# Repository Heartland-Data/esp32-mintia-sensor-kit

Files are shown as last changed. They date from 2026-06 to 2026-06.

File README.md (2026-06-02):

# esp32-mintia-sensor-kit

本リポジトリは、MINTIAケースにESP32と各種センサを組み込む試作用ファームウェアの参考実装です。

Acconeer XM125（存在検知レーダー）、AMG8833（8×8 IRアレイ）、MLX90640（32×24 IRアレイ）の3種のセンサを制御し、計測データをBluetooth Classic (SPP) および UART でホストPCへ送信します。

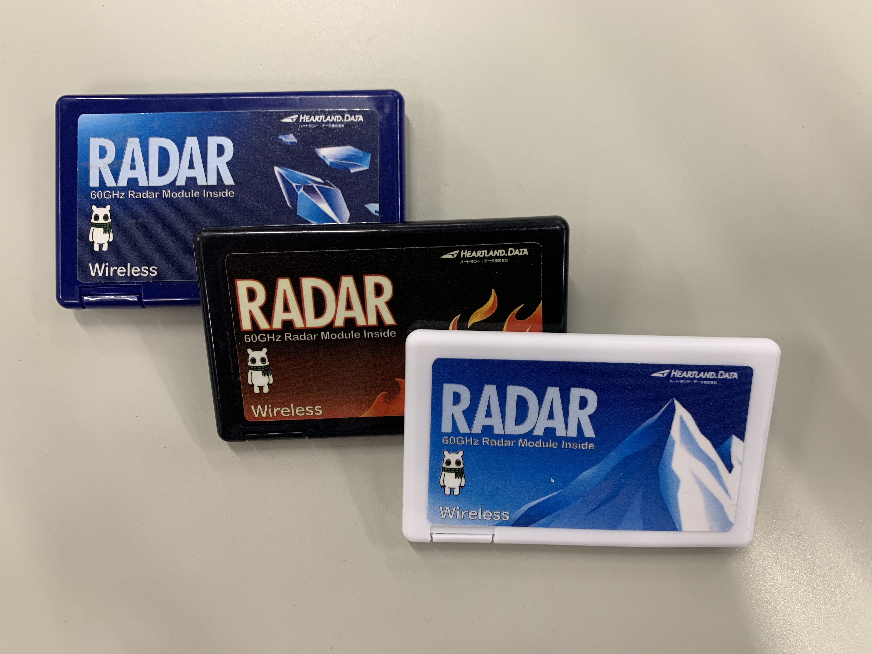
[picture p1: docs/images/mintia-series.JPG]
MINTIAケースシリーズ

MINTIAケース

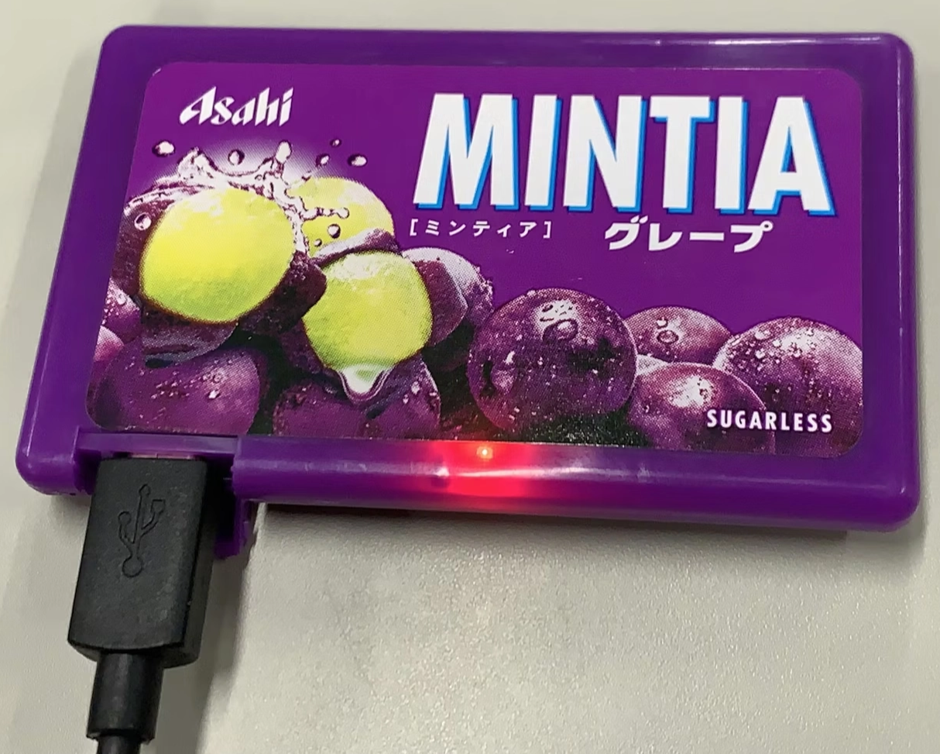
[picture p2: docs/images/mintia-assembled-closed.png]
MINTIAケース収納状態

MINTIAケースに基板を組み込んだ状態の外観です。

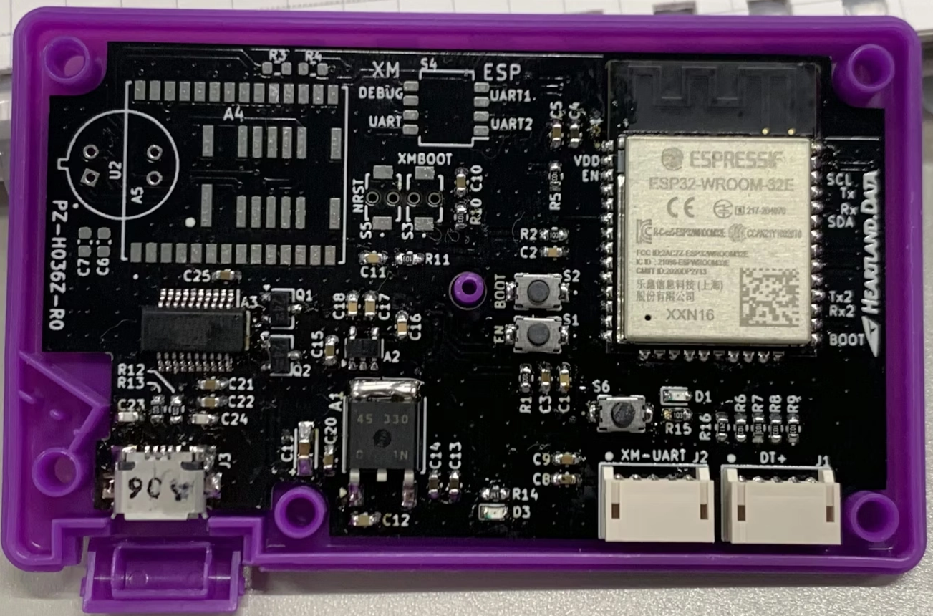
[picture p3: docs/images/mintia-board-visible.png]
MINTIAケース内部基板

ケース上部を開けると、内部の基板を確認できます。

ハードウェア構成、基板設計、部品実装などの詳細については、以下の解説記事を参照してください。

- [MINTIA(清涼菓子) へ ESP32 を組込む ~ 準備編 ~ - Qiita](https://qiita.com/TTL/items/94461dc0f962da8d8ca6)
- [MINTIA(清涼菓子) へ ESP32 を組込む ～ 回路、基板設計 ～ - Qiita](https://qiita.com/TTL/items/4987077ce9cf24eee11f)
- [MINTIA(清涼菓子) へ ESP32 を組込む ～ガーバー出力 ～ - Qiita](https://qiita.com/TTL/items/95624cc8908f53563718)
- [MINTIA(清涼菓子) へ ESP32 を組込む ～基板発注～ - Qiita](https://qiita.com/TTL/items/4f62d206479876ff367e)
- [MINTIA(清涼菓子) へ ESP32 を組込む ～基板到着 -> 部品実装～ - Qiita](https://qiita.com/TTL/items/9614f3e603545a89d696)

## 対応センサ

| センサ | 種別 | 解像度 / 検知方式 |
| --- | --- | --- |
| Acconeer XM125 | レーダーセンサー | I2C 接続、距離・存在検知 |
| AMG8833 (AMG88xx) | IRセンサー | I2C 接続、8×8 ピクセル |
| MLX90640 | IRセンサー | I2C 接続、32×24 ピクセル（768点） |

## ビルド環境

| 項目 | バージョン |
| --- | --- |
| ESP-IDF | v5.4.1 |
| ビルドシステム | CMake + idf.py |
| Bluetooth | Classic (SPP) — `sdkconfig.defaults` で設定済み |

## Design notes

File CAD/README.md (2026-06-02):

# 概要
本リポジトリは、Acconeer社製 60GHz Radar Unit "XM125" 及び "IR Sensor Array",
Espressif社 ESP32 Module を 清涼菓子 "MINTIA"ケースに収まる仕立ての回路及び基板データです。

## ハードウェア構成
* [Espressif ESP32](https://www.espressif.com/ja-jp/products/modules)
* [Acconeer](https://acconeer.com/products/) XM125 (60GHz Radar)
* IR Sensor Array
    * panasonic社 [AMG88](https://industrial.panasonic.com/jp/products/pt/grid-eye/models/AMG8833)
    * Melexis社 [MLX90640](https://www.melexis.com/en/product/MLX90640/far-infrared-thermal-sensor-array)

# ディレクトリ構造
[KiCAD](https://www.kicad.org/) 用 Data 及び PCB作成用ガーバーデータ一式

```
|   README.md
|   IR.kicad_sch
|   Main.kicad_sch
|   Power.kicad_sch
|   Radar.kicad_sch
|   Serial.kicad_sch
|   Work.kicad_pcb
|   Work.kicad_prl
|   Work.kicad_pro
|   Work.kicad_sch
|
\---GB
        PZ-H036Z-R1-B_Cu.gbl
        PZ-H036Z-R1-B_Mask.gbs
        PZ-H036Z-R1-B_Paste.gbp
        PZ-H036Z-R1-B_Silkscreen.gbo
        PZ-H036Z-R1-drl.rpt
        PZ-H036Z-R1-drl_map.gbr
        PZ-H036Z-R1-Edge_Cuts.gm1
        PZ-H036Z-R1-F_Cu.gtl
        PZ-H036Z-R1-F_Mask.gts
        PZ-H036Z-R1-F_Paste.gtp
        PZ-H036Z-R1-F_Silkscreen.gto
        PZ-H036Z-R1.drl
```

# ライセンス
MIT License

Copyright (c) 2026 Heartland Data Co., Ltd.

Permission is hereby granted, free of charge, to any person obtaining a copy of this software and associated documentation files (the "Software"), to deal in the Software without restriction, including without limitation the rights to use, copy, modify, merge, publish, distribute, sublicense, and/or sell copies of the Software, and to permit persons to whom the Software is furnished to do so, subject to the following conditions:

The above copyright notice and this permission notice shall be included in all copies or substantial portions of the Software.

THE SOFTWARE IS PROVIDED "AS IS", WITHOUT WARRANTY OF ANY KIND, EXPRESS OR IMPLIED, INCLUDING BUT NOT LIMITED TO THE WARRANTIES OF MERCHANTABILITY, FITNESS FOR A PARTICULAR PURPOSE AND NONINFRINGEMENT. IN NO EVENT SHALL THE AUTHORS OR COPYRIGHT HOLDERS BE LIABLE FOR ANY CLAIM, DAMAGES OR OTHER LIABILITY, WHETHER IN AN ACTION OF CONTRACT, TORT OR OTHERWISE, ARISING FROM, OUT OF OR IN CONNECTION WITH THE SOFTWARE OR THE USE OR OTHER DEALINGS IN THE SOFTWARE.

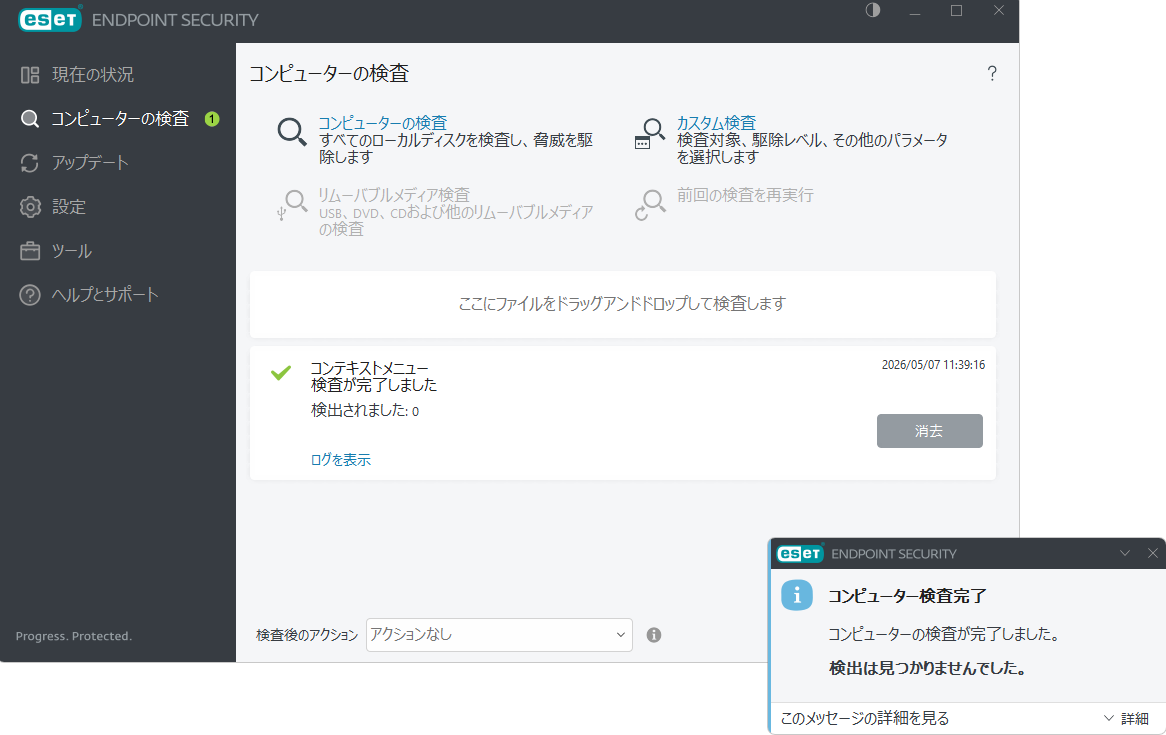
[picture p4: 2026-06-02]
CAD/ESET_Scan.png

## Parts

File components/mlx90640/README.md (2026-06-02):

# MLX90640 ESP32-IDF Library

このライブラリは、SparkFun の MLX90640 IR アレイセンサー用の ESP32-IDF ライブラリです。Arduino 環境向けのコードから ESP32-IDF 向けに移植されています。

## 特徴

- MLX90640 32x24 IR アレイセンサーの完全サポート
- ESP32-IDF I2C ドライバとの統合
- 温度計算と RAW IR イメージデータの取得
- 設定可能なリフレッシュレートと解像度
- 使いやすいサービスクラス

## ファイル構成

```
components/mlx90640/
├── CMakeLists.txt
├── README.md
├── include/
│   ├── mlx90640_api.h          # MLX90640 API関数
│   ├── mlx90640_i2c_driver.h   # I2C通信ドライバ
│   └── mlx90640_service.h      # 高レベルサービスクラス
├── mlx90640_api.c              # MLX90640 API実装
├── mlx90640_i2c_driver.c       # I2C通信ドライバ実装
└── mlx90640_service.c          # 高レベルサービス実装
```

## 使用方法

### 1. 基本的な初期化と温度取得

```c
#include "mlx90640_service.h"

void app_main()
{
    // 設定の初期化
    mlx90640_config_t config = MLX90640_DEFAULT_CONFIG();

    // サービスの初期化
    mlx90640_service_t *mlx_service = mlx90640_service_init(&config);
    if (mlx_service == NULL) {
        ESP_LOGE("APP", "Failed to initialize MLX90640 service");
        return;
    }

    // 温度データ配列 (24x32 = 768個)
    float temperatures[768];

    while (1) {
        // 温度データの取得
        esp_err_t ret = mlx90640_service_get_temperatures(mlx_service, temperatures);
        if (ret == ESP_OK) {
            // 温度データの処理
            for (int i = 0; i < 768; i++) {
                printf("%.2f,", temperatures[i]);
                if ((i + 1) % 32 == 0) printf("\n");
            }
        }

        vTaskDelay(pdMS_TO_TICKS(500)); // 500ms待機
    }

    // クリーンアップ
    mlx90640_service_deinit(mlx_service);
}
```

### 2. 既存のタスクシステムとの統合

```c
#include "mlx90640_service.h"

// タスククラスのヘッダで
class YourIrSensorTask {
private:
    mlx90640_service_t *mlx_service_;

public:
    bool Initialize() {
        mlx90640_config_t config = MLX90640_DEFAULT_CONFIG();
        // カスタム設定
        config.sda_pin = 21;
        config.scl_pin = 22;
        config.refresh_rate = 0x03; // 4Hz

        mlx_service_ = mlx90640_service_init(&config);
        return (mlx_service_ != nullptr);
    }

    void Run() {
        float temperatures[768];
        esp_err_t ret = mlx90640_service_get_temperatures(mlx_service_, temperatures);
        if (ret == ESP_OK) {
            // データをメッセージバッファに送信
            SendSensorData((uint8_t*)temperatures, sizeof(temperatures));
        }
    }

    ~YourIrSensorTask() {
        if (mlx_service_) {
            mlx90640_service_deinit(mlx_service_);
        }
    }
};
```

### 3. 低レベル API 使用例

```c
#include "mlx90640_api.h"
#include "mlx90640_i2c_driver.h"

void low_level_example()
{
    // I2C初期化
    MLX90640_I2CInit(I2C_NUM_0, 21, 22, 400000);

    uint8_t mlx_addr = 0x33;
    uint16_t eeMLX90640[832];
    paramsMLX90640 mlx90640;

    // EEPROM読み込み
    int status = MLX90640_DumpEE(mlx_addr, eeMLX90640);
    if (status != 0) {
        ESP_LOGE("MLX", "Failed to load system parameters");
        return;
    }

    // パラメータ抽出
    status = MLX90640_ExtractParameters(eeMLX90640, &mlx90640);
    if (status != 0) {
        ESP_LOGE("MLX", "Parameter extraction failed");
        return;
    }

    // リフレッシュレート設定
    MLX90640_SetRefreshRate(mlx_addr, 0x03); // 4Hz

    uint16_t mlx90640Frame[834];
    float mlx90640To[768];

    while (1) {
        // フレームデータ取得
        status = MLX90640_GetFrameData(mlx_addr, mlx90640Frame);
        if (status < 0) {
            ESP_LOGE("MLX", "GetFrame Error: %d", status);
            continue;
        }

        float vdd = MLX90640_GetVdd(mlx90640Frame, &mlx90640);
        float ta = MLX90640_GetTa(mlx90640Frame, &mlx90640);
        float tr = ta - 8; // 反射温度
        float emissivity = 0.95;

        // 温度計算
        MLX90640_CalculateTo(mlx90640Frame, &mlx90640, emissivity, tr, mlx90640To);

        // データ処理
        for (int x = 0; x < 768; x++) {
            printf("%.2f,", mlx90640To[x]);
        }
        printf("\n");

        vTaskDelay(pdMS_TO_TICKS(250));
    }
}
```

## 設定パラメータ

### リフレッシュレート

- 0x00: 0.5Hz
- 0x01: 1Hz
- 0x02: 2Hz
- 0x03: 4Hz (推奨)
- 0x04: 8Hz
- 0x05: 16Hz
- 0x06: 32Hz
- 0x07: 64Hz

### 解像度

- 0x00: 16 ビット
- 0x01: 17 ビット (推奨)
- 0x02: 18 ビット
- 0x03: 19 ビット

## ハードウェア接続

```
ESP32    MLX90640
-----    --------
3.3V  -> VCC
GND   -> GND
21    -> SDA
22    -> SCL
```

プルアップ抵抗（4.7kΩ）が SDA と SCL ラインに必要です。

## トラブルシューティング

### I2C 通信エラー

- 配線を確認してください
- プルアップ抵抗が正しく接続されているか確認してください
- I2C アドレス（デフォルト：0x33）を確認してください

### データ取得エラー

- センサーの電源投入後、100ms 以上待機してください
- フレームレート設定を下げてみてください

## ライセンス

このライブラリは **Apache License 2.0** の下でライセンスされています（`LICENSE` ファイル参照）。

### 著作権表示・帰属情報

本コードは以下の著作物を元に派生したものです。

| 著作物 | 著作権者 | ライセンス | URL |
|---|---|---|---|
| MLX90640 library (オリジナル) | © 2017 Melexis N.V. | Apache License 2.0 | https://github.com/melexis/mlx90640-library |
| Qwiic IR Array MLX90640 Firmware (Arduino 移植) | SparkFun Electronics | Apache License 2.0 ※ | https://github.com/sparkfun/Qwiic_IR_Array_MLX90640 |
| 本ライブラリ (ESP32-IDF 移植・改変) | © 2025 Heartland.Data Inc. | Apache License 2.0 | — |

※ SparkFun のファームウェアは Melexis の Apache License 2.0 ヘッダをそのまま維持しています。

Apache License 2.0 の全文は [http://www.apache.org/licenses/LICENSE-2.0](http://www.apache.org/licenses/LICENSE-2.0) を参照してください。

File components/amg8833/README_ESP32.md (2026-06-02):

# AMG88xx ESP32 Driver

ESP-IDF対応のAMG88xx赤外線温度センサードライバーです。

## 概要

このライブラリは、Panasonic AMG88xx (AMG8833) 赤外線アレイセンサーをESP32で使用するためのESP-IDF互換ドライバーです。Arduino環境の依存関係を取り除き、ESP-IDFのAPIを使用して実装されています。

## 特徴

- ESP-IDF v4.4以降対応
- C言語インターフェース
- 8x8ピクセルの温度データ読み取り
- サーミスタ温度読み取り
- 割り込み機能サポート
- 移動平均フィルタ
- パワーマネジメント
- フレームレート設定（1FPS/10FPS）

## ハードウェア要件

- ESP32系マイコン
- AMG8833赤外線アレイセンサー
- I2C接続（SCL, SDA）

## 配線

| AMG8833 | ESP32 |
|---|---|
| VDD | 3.3V  |
| GND | GND |
| SCL | GPIO22 (設定可能) |
| SDA | GPIO21 (設定可能) |
| INT | GPIO (オプション) |

## 使用方法

### 1. I2Cの初期化

```c
#include "driver/i2c.h"

static esp_err_t i2c_master_init(void)
{
    i2c_config_t conf = {
        .mode = I2C_MODE_MASTER,
        .sda_io_num = 21,
        .scl_io_num = 22,
        .sda_pullup_en = GPIO_PULLUP_ENABLE,
        .scl_pullup_en = GPIO_PULLUP_ENABLE,
        .master.clk_speed = 400000,
    };

    esp_err_t err = i2c_param_config(I2C_NUM_0, &conf);
    if (err != ESP_OK) {
        return err;
    }

    return i2c_driver_install(I2C_NUM_0, conf.mode, 0, 0, 0);
}
```

### 2. AMG88xxの初期化

```c
#include "amg88xx_esp32.h"

amg88xx_handle_t amg_handle;
amg88xx_config_t amg_config = {
    .i2c_port = I2C_NUM_0,
    .device_address = AMG88XX_ADDRESS,
    .timeout_ms = 1000
};

esp_err_t ret = amg88xx_init(&amg_handle, &amg_config);
if (ret != ESP_OK) {
    ESP_LOGE(TAG, "Failed to initialize AMG88xx");
    return;
}
```

### 3. 温度データの読み取り

```c
// ピクセル温度の読み取り
float pixels[AMG88XX_PIXEL_ARRAY_SIZE];
ret = amg88xx_read_pixels(&amg_handle, pixels, AMG88XX_PIXEL_ARRAY_SIZE);
if (ret == ESP_OK) {
    // 8x8の温度データを処理
    for (int i = 0; i < 64; i++) {
        printf("Pixel %d: %.2f°C\n", i, pixels[i]);
    }
}

// サーミスタ温度の読み取り
float thermistor_temp;
ret = amg88xx_read_thermistor(&amg_handle, &thermistor_temp);
if (ret == ESP_OK) {
    printf("Thermistor: %.2f°C\n", thermistor_temp);
}
```

### 4. 設定変更

```c
// フレームレート設定
amg88xx_set_frame_rate(&amg_handle, AMG88XX_FPS_10);

// 移動平均フィルタ
amg88xx_set_moving_average_mode(&amg_handle, true);

// パワーモード設定
amg88xx_set_power_mode(&amg_handle, AMG88XX_NORMAL_MODE);
```

### 5. 割り込み設定

```c
// 割り込みレベル設定
amg88xx_set_interrupt_levels(&amg_handle, 30.0f, 25.0f);

// 割り込み有効化
amg88xx_enable_interrupt(&amg_handle);

// 割り込みモード設定
amg88xx_set_interrupt_mode(&amg_handle, AMG88XX_ABSOLUTE_VALUE);
```

## API リファレンス

### 初期化・終了処理

- `amg88xx_init()` - センサーの初期化
- `amg88xx_deinit()` - センサーの終了処理

### データ読み取り

- `amg88xx_read_pixels()` - ピクセル温度データ読み取り（float値）
- `amg88xx_read_pixels_raw()` - ピクセル温度データ読み取り（生データ）
- `amg88xx_read_thermistor()` - サーミスタ温度読み取り

### 設定

- `amg88xx_set_power_mode()` - パワーモード設定
- `amg88xx_set_frame_rate()` - フレームレート設定
- `amg88xx_set_moving_average_mode()` - 移動平均フィルタ設定
- `amg88xx_software_reset()` - ソフトウェアリセット

### 割り込み

- `amg88xx_enable_interrupt()` - 割り込み有効化
- `amg88xx_disable_interrupt()` - 割り込み無効化
- `amg88xx_set_interrupt_mode()` - 割り込みモード設定
- `amg88xx_set_interrupt_levels()` - 割り込みレベル設定
- `amg88xx_get_interrupt()` - 割り込み状態読み取り
- `amg88xx_clear_interrupt()` - 割り込みクリア

## サンプルコード

詳細な使用例は `amg88xx_example.c` を参照してください。

## ライセンス

このドライバは Adafruit 社の AMG88xx Arduino ライブラリ
([https://github.com/adafruit/Adafruit_AMG88xx](https://github.com/adafruit/Adafruit_AMG88xx))
を基に ESP-IDF 向けに移植したものです。

**元ライブラリの著作権表示：**

```
MIT License

Copyright (c) Adafruit Industries
Written by Dean Miller for Adafruit Industries
```

本ファイルを含む派生著作物には MIT ライセンスが適用されます。
ライセンス全文は `LICENSE` ファイルを参照してください。

## 注意事項

1. I2Cバスは事前に初期化されている必要があります
2. センサーの電源は3.3Vを使用してください
3. プルアップ抵抗がI2C信号線に必要です
4. センサーの視野角は60度です
5. 動作温度範囲：-20°C ～ +80°C
6. 測定温度範囲：0°C ～ +80°C

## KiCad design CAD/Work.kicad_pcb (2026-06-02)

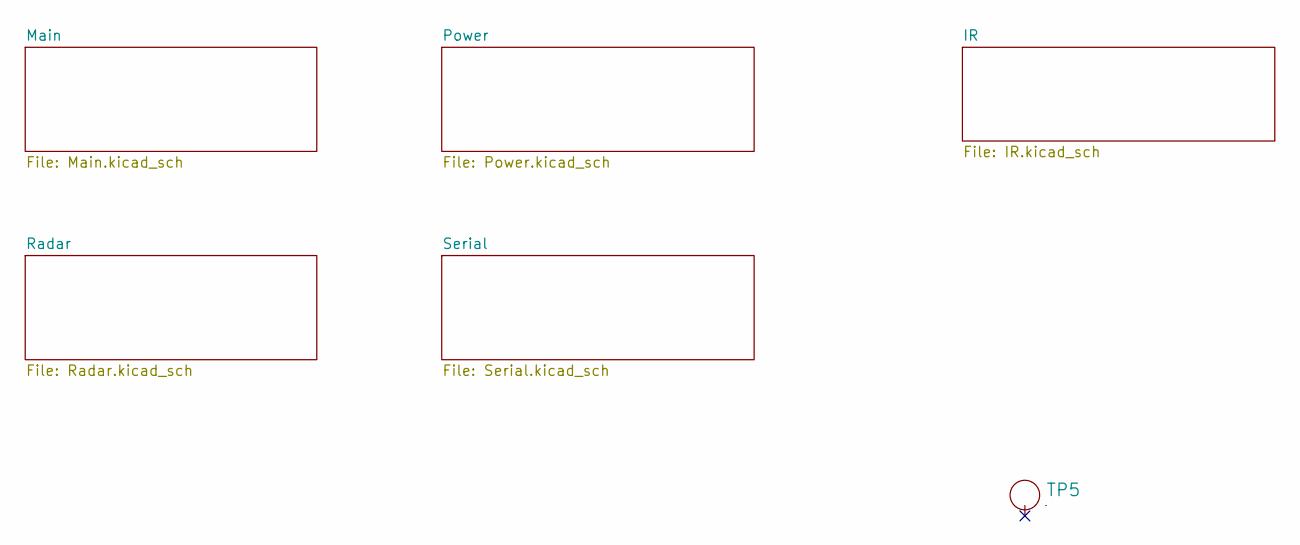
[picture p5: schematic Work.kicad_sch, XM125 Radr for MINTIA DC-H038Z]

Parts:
TP5: TP_FL; HLDC_logo2

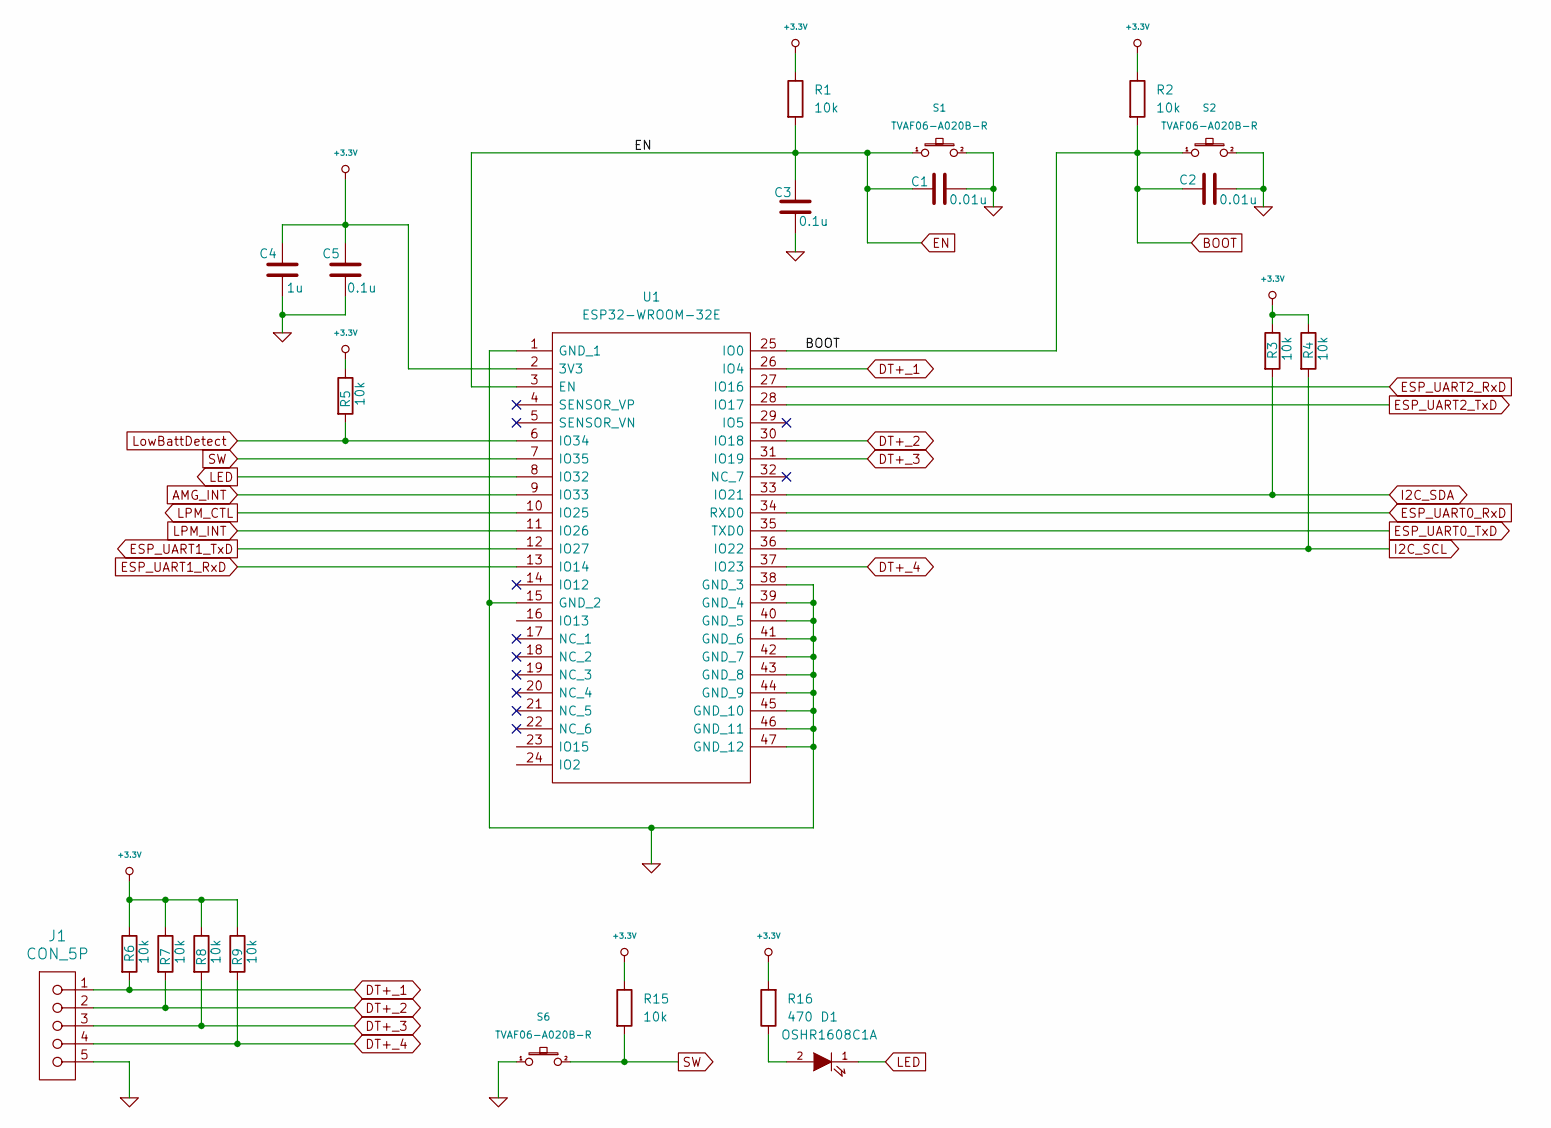
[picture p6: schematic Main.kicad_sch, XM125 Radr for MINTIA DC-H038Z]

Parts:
C1, C2: 0.01u; C_0603_1608Metric; PARTNUMBER GRM1882C1H103JA01
C3, C5: 0.1u; C_0603_1608Metric; PARTNUMBER GRM188R72A104MA35
C4: 1u; C_0603_1608Metric; PARTNUMBER GRM185R61C105KE44
D1: OSHR1608C1A; D_0603; PARTNUMBER OSHR1608C1A
J1: CON_5P; CONN_S5B-ZR_JST; PARTNUMBER S5B-ZR
R1, R2, R3, R4, R5, R6, R7, R8, R9, R15: 10k; R_0603_1608Metric; PARTNUMBER ERJ3GEYJ103V
R16: 470; R_0603_1608Metric; PARTNUMBER ERJ3GEYJ471V
S1, S2, S6: TVAF06-A020B-R; TVAF06A020BR; PARTNUMBER TVAF06-A020B-R
U1: ESP32-WROOM-32E; ESP32WROOM32E-Hole; Manufacturer_Part_Number ESP32-WROOM-32E

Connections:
+3.3V: C4.2, C5.2, R1.1, R2.1, R3.1, R4.1, R5.1, R6.1, R7.1, R8.1, R9.1, R15.1, R16.2, U1.2 (3V3); also elsewhere on the board
AMG_INT: U1.9 (IO33); also elsewhere on the board
BOOT: C2.2, R2.2, S2.1, U1.25 (IO0); also elsewhere on the board
DT+_1: J1.1, R6.2, U1.26 (IO4)
DT+_2: J1.2, R7.2, U1.30 (IO18)
DT+_3: J1.3, R8.2, U1.31 (IO19)
DT+_4: J1.4, R9.2, U1.37 (IO23)
EN: C1.2, C3.1, R1.2, S1.1, U1.3 (EN); also elsewhere on the board
ESP_UART0_RxD: U1.34 (RXD0); also elsewhere on the board
ESP_UART0_TxD: U1.35 (TXD0); also elsewhere on the board
ESP_UART1_RxD: U1.13 (IO14); also elsewhere on the board
ESP_UART1_TxD: U1.12 (IO27); also elsewhere on the board
ESP_UART2_RxD: U1.27 (IO16); also elsewhere on the board
ESP_UART2_TxD: U1.28 (IO17); also elsewhere on the board
GND: C1.1, C2.1, C3.2, C4.1, C5.1, J1.5, S1.2, S2.2, S6.1, U1.1 (GND_1), U1.15 (GND_2), U1.38 (GND_3), U1.39 (GND_4), U1.40 (GND_5), U1.41 (GND_6), U1.42 (GND_7), U1.43 (GND_8), U1.44 (GND_9), U1.45 (GND_10), U1.46 (GND_11), U1.47 (GND_12); also elsewhere on the board
I2C_SCL: R4.2, U1.36 (IO22); also elsewhere on the board
I2C_SDA: R3.2, U1.33 (IO21); also elsewhere on the board
LED: D1.1 (K), U1.8 (IO32)
LPM_CTL: U1.10 (IO25); also elsewhere on the board
LPM_INT: U1.11 (IO26); also elsewhere on the board
LowBattDetect: R5.2, U1.6 (IO34)
unnamed: D1.2 (A), R16.1
SW: R15.2, S6.2, U1.7 (IO35)

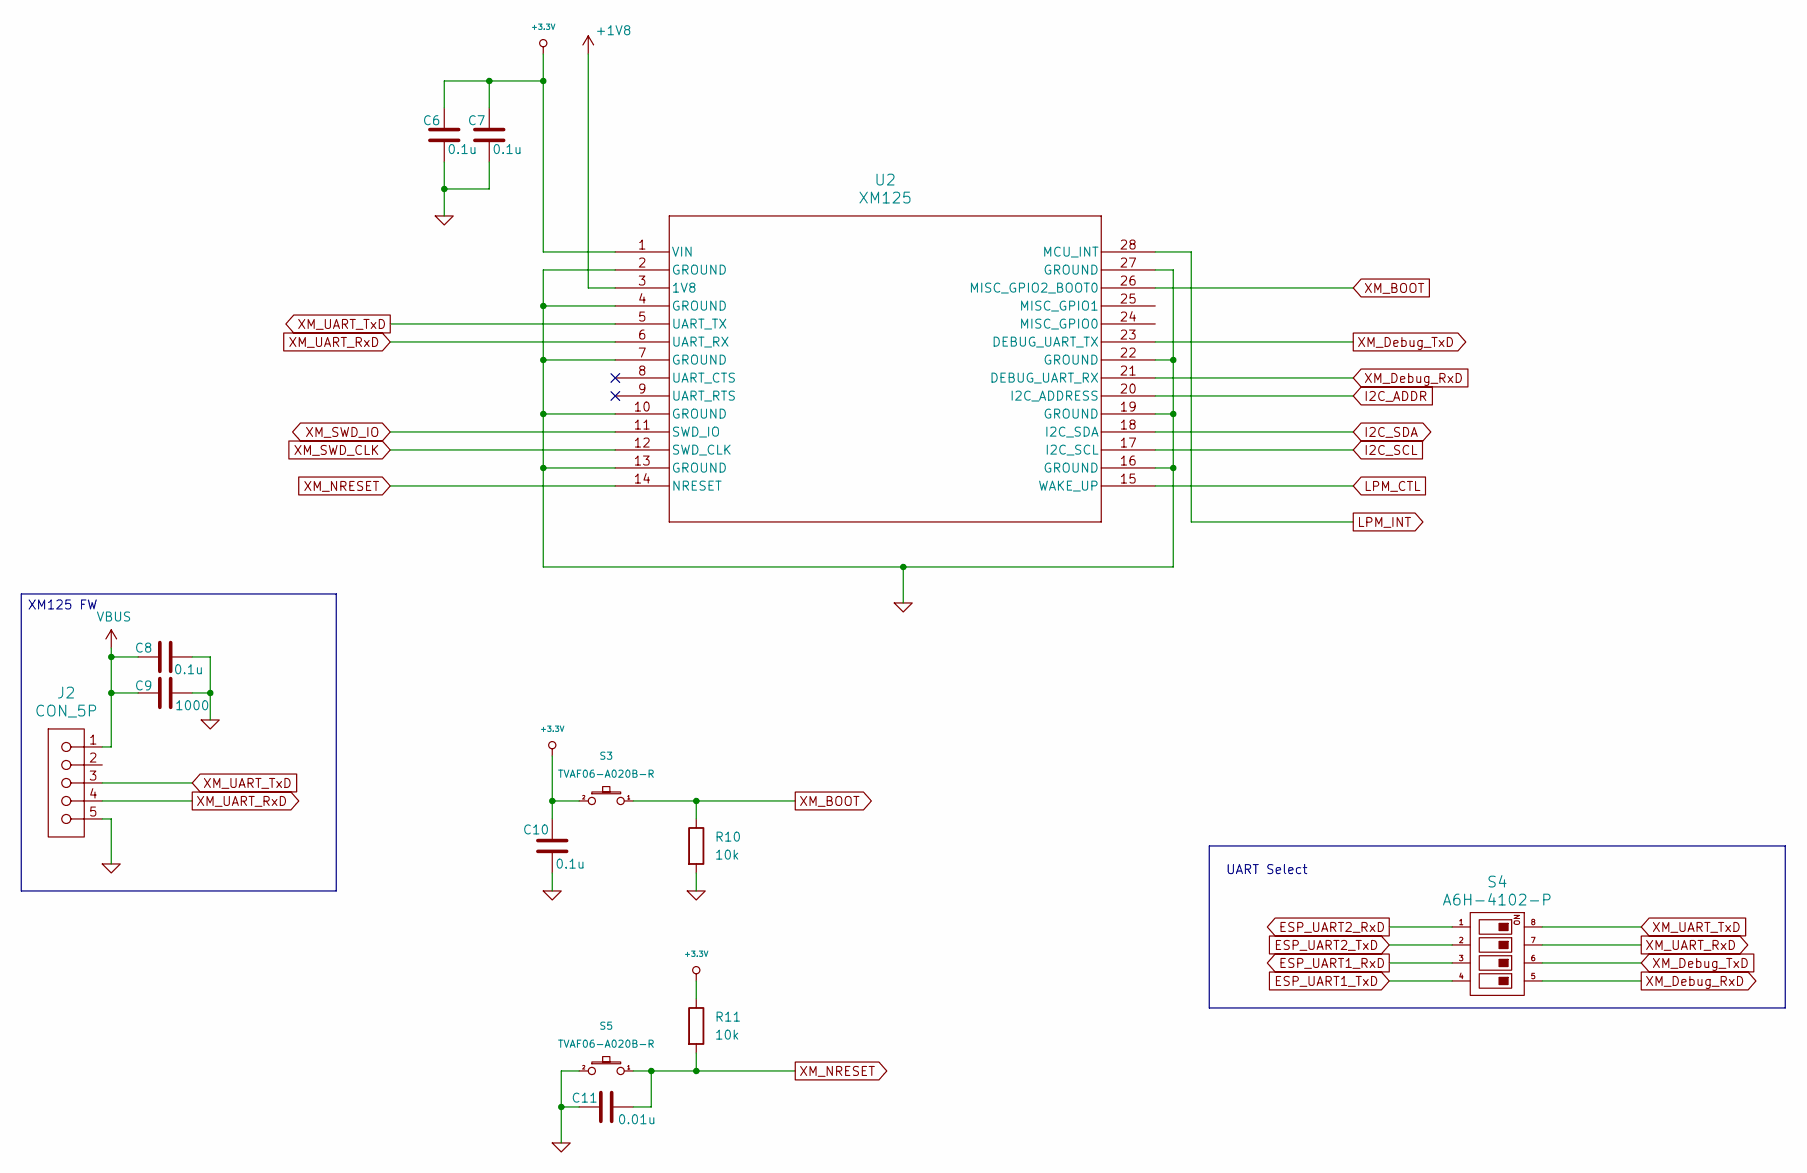
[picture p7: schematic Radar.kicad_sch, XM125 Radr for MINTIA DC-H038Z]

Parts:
C6, C7, C8, C10: 0.1u; C_0603_1608Metric; PARTNUMBER GRM188R72A104MA35
C9: 1000; C_0603_1608Metric; PARTNUMBER GRM1882C1H102JA01
C11: 0.01u; C_0603_1608Metric; PARTNUMBER GRM1882C1H103JA01
J2: CON_5P; CONN_S5B-ZR_JST; PARTNUMBER S5B-ZR
R10, R11: 10k; R_0603_1608Metric; PARTNUMBER ERJ3GEYJ103V
S3, S5: TVAF06-A020B-R; TVAF06A020BR; PARTNUMBER TVAF06-A020B-R
S4: A6H-4102-P; SOIC127P812X230-8N; PARTNUMBER A6H-4102-P
U2: XM125; XM125_ACC; PARTNUMBER XM125

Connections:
+1V8: U2.3 (1V8); also elsewhere on the board
+3.3V: C6.1, C7.1, C10.1, R11.1, S3.2, U2.1 (VIN); also elsewhere on the board
ESP_UART1_RxD: S4.3; also elsewhere on the board
ESP_UART1_TxD: S4.4; also elsewhere on the board
ESP_UART2_RxD: S4.1; also elsewhere on the board
ESP_UART2_TxD: S4.2; also elsewhere on the board
GND: C6.2, C7.2, C8.1, C9.1, C10.2, C11.2, J2.5, R10.2, S5.2, U2.2 (GROUND), U2.4 (GROUND), U2.7 (GROUND), U2.10 (GROUND), U2.13 (GROUND), U2.16 (GROUND), U2.19 (GROUND), U2.22 (GROUND), U2.27 (GROUND); also elsewhere on the board
I2C_ADDR: U2.20 (I2C_ADDRESS)
I2C_SCL: U2.17 (I2C_SCL); also elsewhere on the board
I2C_SDA: U2.18 (I2C_SDA); also elsewhere on the board
LPM_CTL: U2.15 (WAKE_UP); also elsewhere on the board
LPM_INT: U2.28 (MCU_INT); also elsewhere on the board
VBUS: C8.2, C9.2, J2.1; also elsewhere on the board
XM_BOOT: R10.1, S3.1, U2.26 (MISC_GPIO2_BOOT0)
XM_Debug_RxD: S4.5, U2.21 (DEBUG_UART_RX)
XM_Debug_TxD: S4.6, U2.23 (DEBUG_UART_TX)
XM_NRESET: C11.1, R11.2, S5.1, U2.14 (NRESET)
XM_SWD_CLK: U2.12 (SWD_CLK)
XM_SWD_IO: U2.11 (SWD_IO)
XM_UART_RxD: J2.4, S4.7, U2.6 (UART_RX)
XM_UART_TxD: J2.3, S4.8, U2.5 (UART_TX)

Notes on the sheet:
UART Select
XM125 FW

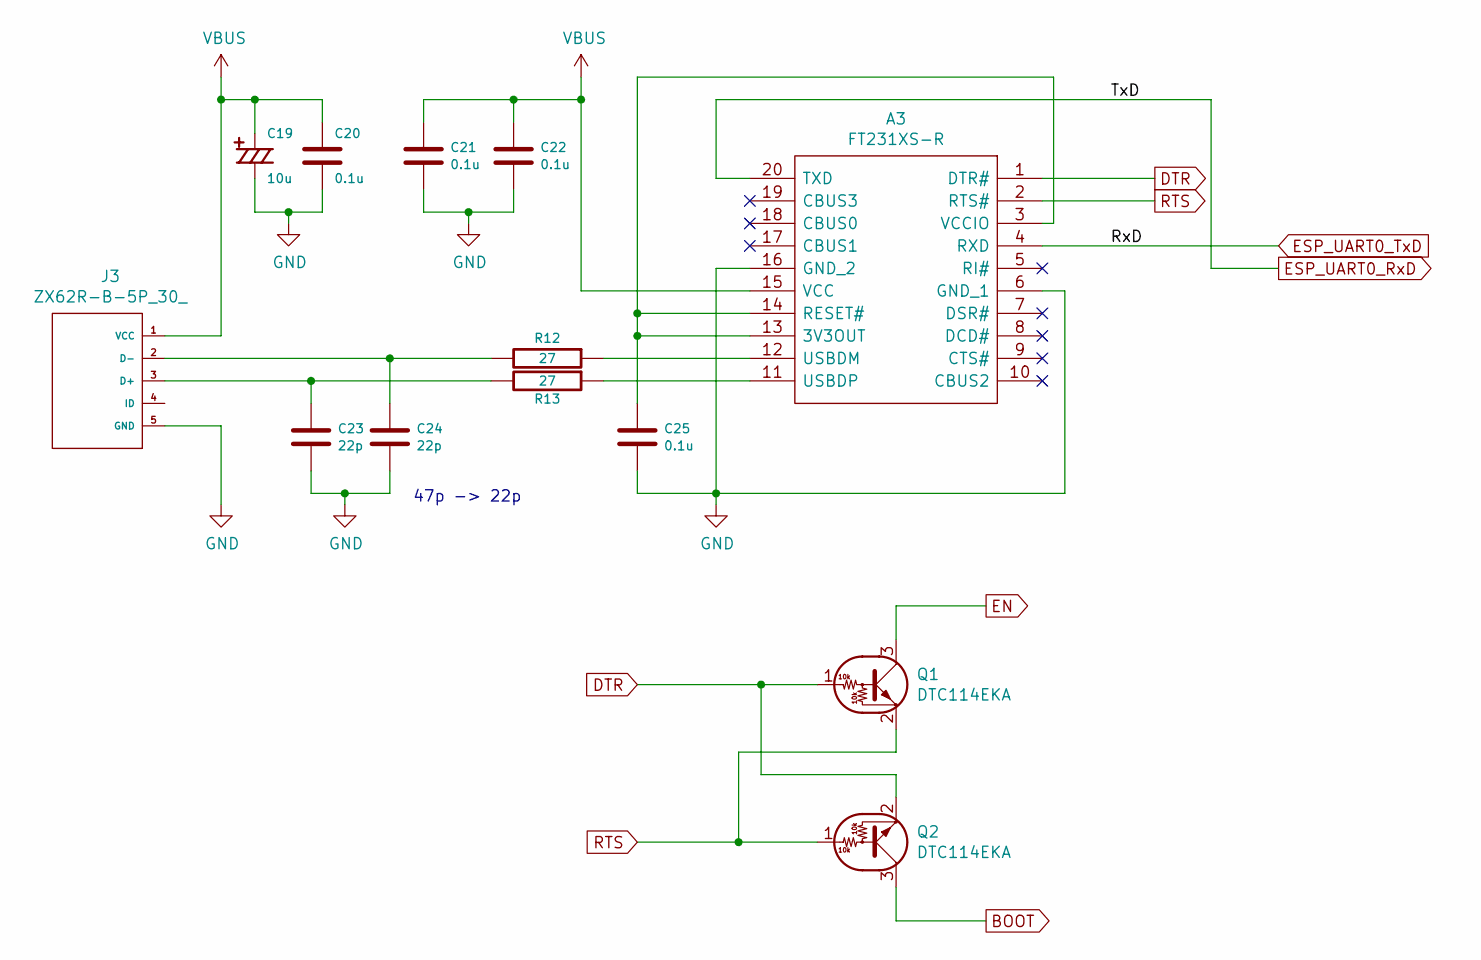
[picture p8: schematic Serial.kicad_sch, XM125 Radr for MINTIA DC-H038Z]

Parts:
A3: FT231XS-R; SOP64P599X175-20N; Manufacturer_Part_Number FT231XS-R
C19: 10u; F920J106MPA; PARTNUMBER F920J106MPA
C20, C21, C22, C25: 0.1u; C_0603_1608Metric; PARTNUMBER GRM188R72A104MA35
C23, C24: 22p; C_0603_1608Metric; PARTNUMBER GRM1885C2E220FW07
J3: ZX62R-B-5P_30_; ZX62R-B-5P_30; PARTNUMBER ZX62R-B-5P(30)
Q1, Q2: DTC114EKA; SC-59; PARTNUMBER DTC114EKA
R12, R13: 27; R_0603_1608Metric; PARTNUMBER ERJ3GEYJ270V

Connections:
BOOT: Q2.3 (C); also elsewhere on the board
DTR: A3.1 (DTR#), Q1.1 (B), Q2.2 (E)
EN: Q1.3 (C); also elsewhere on the board
ESP_UART0_RxD: A3.20 (TXD); also elsewhere on the board
ESP_UART0_TxD: A3.4 (RXD); also elsewhere on the board
GND: A3.6 (GND_1), A3.16 (GND_2), C19.2, C20.2, C21.2, C22.2, C23.2, C24.2, C25.2, J3.5 (GND); also elsewhere on the board
unnamed: A3.3 (VCCIO), A3.13 (3V3OUT), A3.14 (RESET#), C25.1
unnamed: A3.12 (USBDM), R12.1
unnamed: A3.11 (USBDP), R13.1
unnamed: C23.1, J3.3 (D+), R13.2
unnamed: C24.1, J3.2 (D-), R12.2
RTS: A3.2 (RTS#), Q1.2 (E), Q2.1 (B)
VBUS: A3.15 (VCC), C19.1, C20.1, C21.1, C22.1, J3.1 (VCC); also elsewhere on the board

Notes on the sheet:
47p -> 22p

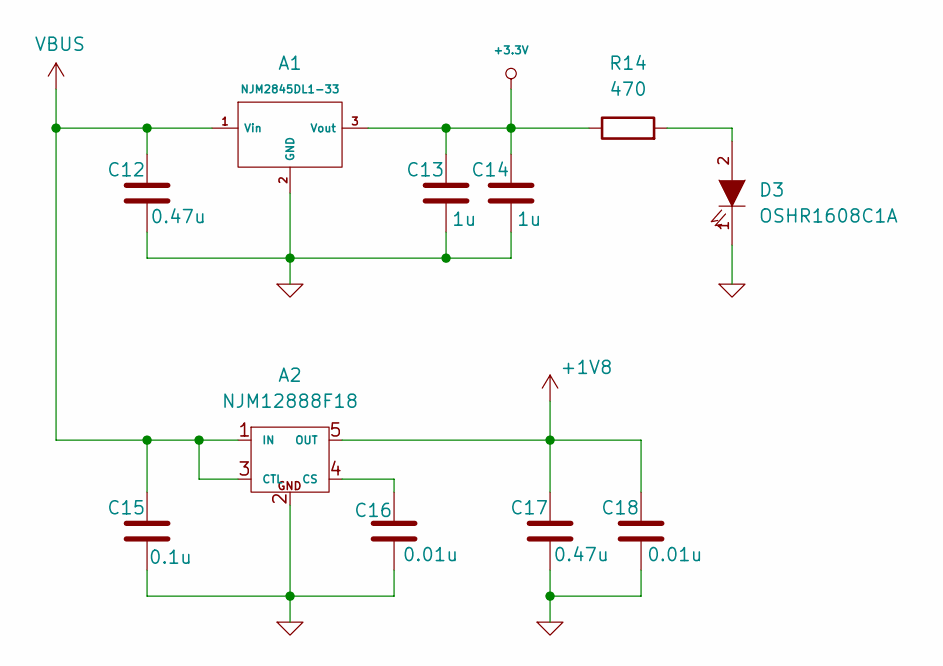
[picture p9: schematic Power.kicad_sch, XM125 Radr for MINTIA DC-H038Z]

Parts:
A1: NJM2845DL1-33; TO-252-2; PARTNUMBER NJM2845DL1-33
A2: NJM12888F18; SOT-23-5; PARTNUMBER NJM12888F18
C12, C17: 0.47u; C_0603_1608Metric; PARTNUMBER GRM188R71C474KA88
C13, C14: 1u; C_0603_1608Metric; PARTNUMBER GRM185R61C105KE44
C15: 0.1u; C_0603_1608Metric; PARTNUMBER GRM188R72A104MA35
C16, C18: 0.01u; C_0603_1608Metric; PARTNUMBER GRM1882C1H103JA01
D3: OSHR1608C1A; D_0603; PARTNUMBER OSHR1608C1A
R14: 470; R_0603_1608Metric; PARTNUMBER ERJ3GEYJ471V

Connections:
+1V8: A2.5 (OUT), C17.2, C18.2; also elsewhere on the board
+3.3V: A1.3 (Vout), C13.2, C14.2, R14.1; also elsewhere on the board
GND: A1.2 (GND), A2.2 (GND), C12.1, C13.1, C14.1, C15.1, C16.1, C17.1, C18.1, D3.1 (K); also elsewhere on the board
unnamed: A2.4 (CS), C16.2
unnamed: D3.2 (A), R14.2
VBUS: A1.1 (Vin), A2.1 (IN), A2.3 (CTL), C12.2, C15.2; also elsewhere on the board

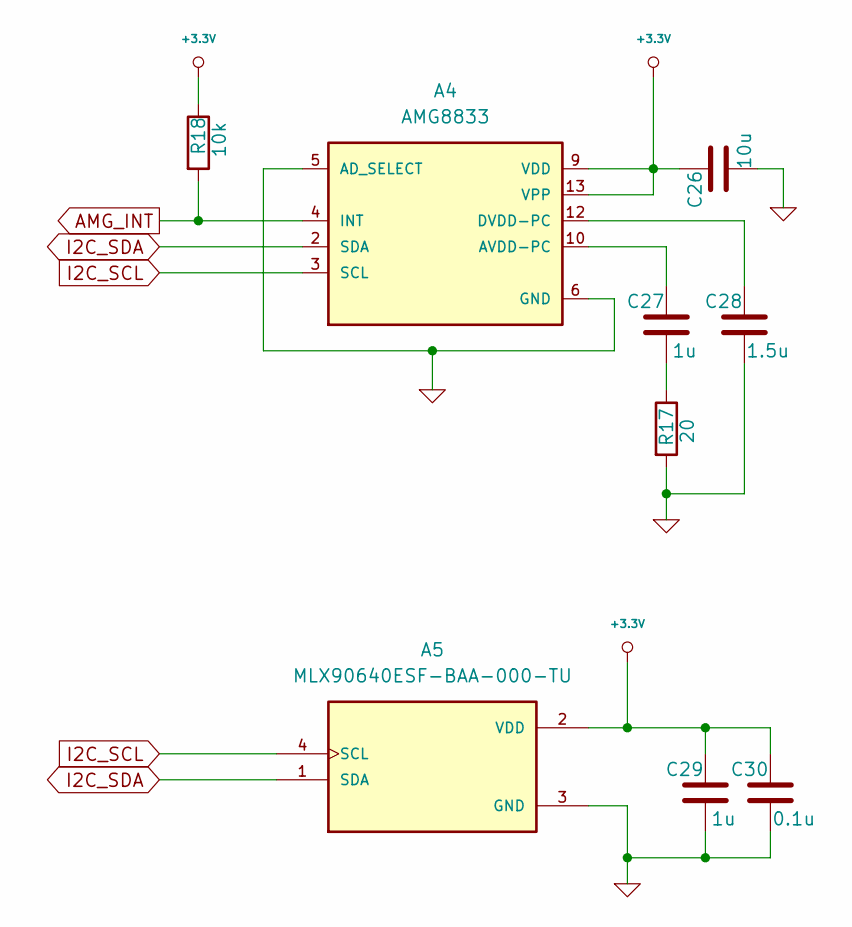
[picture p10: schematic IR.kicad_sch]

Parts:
A4: AMG8833; XDCR_AMG8833; PARTNUMBER AMG8833
A5: MLX90640ESF-BAA-000-TU; TO292P930H600-4; PARTREV 11
C26: 10u; C_0603_1608Metric; PARTNUMBER GRM188C81C106MA73
C27, C29: 1u; C_0603_1608Metric; PARTNUMBER GRM185R61C105KE44
C28: 1.5u; C_0603_1608Metric; PARTNUMBER CGA3E1X5R1C155K080AC
C30: 0.1u; C_0603_1608Metric; PARTNUMBER GRM188R72A104MA35
R17: 20; R_0603_1608Metric; PARTNUMBER ERJ3GEYJ200V
R18: 10k; R_0603_1608Metric; PARTNUMBER ERJ3GEYJ103V

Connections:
+3.3V: A4.9 (VDD), A4.13 (VPP), A5.2 (VDD), C26.2, C29.2, C30.2, R18.1; also elsewhere on the board
AMG_INT: A4.4 (INT), R18.2; also elsewhere on the board
GND: A4.5 (AD_SELECT), A4.6 (GND), A5.3 (GND), C26.1, C28.1, C29.1, C30.1, R17.2; also elsewhere on the board
I2C_SCL: A4.3 (SCL), A5.4 (SCL); also elsewhere on the board
I2C_SDA: A4.2 (SDA), A5.1 (SDA); also elsewhere on the board
unnamed: A4.10 (AVDD-PC), C27.2
unnamed: A4.12 (DVDD-PC), C28.2
unnamed: C27.1, R17.1

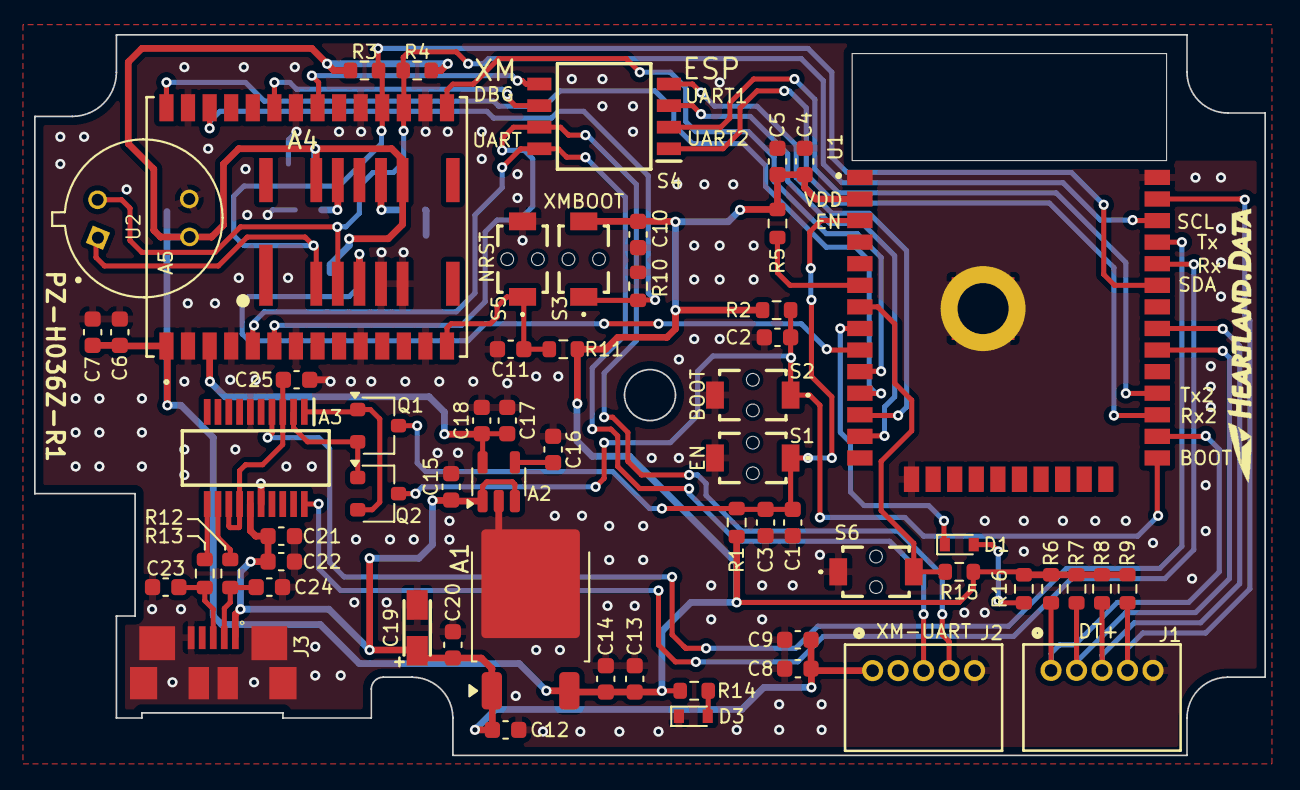
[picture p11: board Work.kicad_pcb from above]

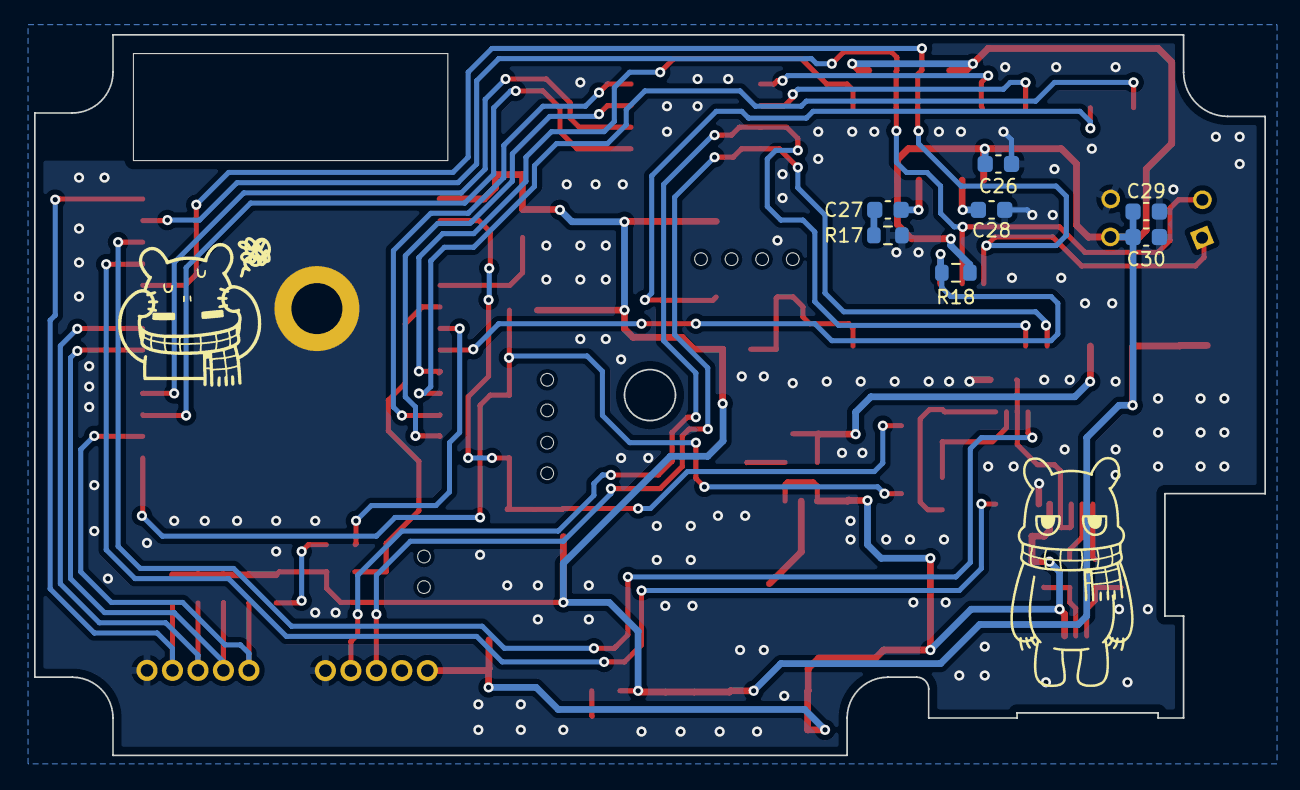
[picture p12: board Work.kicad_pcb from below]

Board: 2 copper layers, 72.4 x 42.4 mm, 69 parts (7 on the bottom side), 43 nets.

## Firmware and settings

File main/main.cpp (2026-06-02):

/**
 * @file main.cpp
 * @brief ESP32 ファームウェア エントリーポイント
 * @copyright Copyright (C) 2026, Heartland Data inc. All Rights Reserved.
 * SPDX-FileCopyrightText: 2026 Heartland Data inc.
 * SPDX-License-Identifier: Apache-2.0
 */

#include <vector>
#include <memory>
#include "uart_log.h"
#include "freertos/FreeRTOS.h"
#include "freertos/task.h"
#include "abstract_task.hpp"
#include "task_sensor.hpp"
#include "task_communication.hpp"
#include "task_data_parser.hpp"
#include "freertos/queue.h"
#include "domain/command_interface/sensor_command.hpp"
#include "task/message_buffer_defs.hpp"
// DT_INCLUDE

std::vector<std::shared_ptr<Task::AbstractTask>> tasks;

/**
 * @brief FreeRTOSタスクの生成
 *
 */
void CreateTask()
{
  // メッセージバッファとキューの生成
  MessageBufferHandle_t rxMessageBuffer = xMessageBufferCreate(kRxMessageBufferSize);
  MessageBufferHandle_t txMessageBuffer = xMessageBufferCreate(kTxMessageBufferSize);
  QueueHandle_t sensorCommandQueue = xQueueCreate(kCommandQueueLength, sizeof(Domain::CommandInterface::SensorCommandMsg));

  // DataParserService/TaskDataParser生成
  tasks.emplace_back(std::make_shared<Task::TaskDataParser>(rxMessageBuffer, txMessageBuffer, sensorCommandQueue));

  // UART通信サービス生成
  tasks.emplace_back(std::make_shared<Task::TaskCommunication>(rxMessageBuffer, txMessageBuffer));

  // AMG88xx センササービスとタスクを生成
  tasks.emplace_back(std::make_shared<Task::SensorTask>(sensorCommandQueue, txMessageBuffer));

  for (auto &task : tasks)
  {
    task->CreateTask(0); // コア0でタスク生成
  }
}

extern "C" void app_main(void)
{
  // UART2を初期化してログ出力先を変更
  init_uart2_for_log();

  CreateTask();
}

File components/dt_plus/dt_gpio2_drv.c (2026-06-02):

// SPDX-FileCopyrightText: 2026 Heartland Data inc.
// SPDX-License-Identifier: Apache-2.0

/*==============================================================================*/
/*  Copyright (C) 2026, Heartland Data inc. All Rights Reserved.                */
/*                                                                              */
/*  Title  :   GPIO 2bit Driver                                                 */
/*  EventID:   Via ther driver                                                  */
/*  AppVer :   DT+ Ver1.00`                                                     */
/*  FileID :   13b                                                              */
/*  Version:   1.0                                                              */
/*  Author :   HLDC                                                             */
/*==============================================================================*/

/*==============================================================================*/
/*  Please customize the code for your environment.                             */
/*==============================================================================*/

/*==============================================================================*/
/*  Desc:   Header for Port Control                                             */
/*==============================================================================*/
#include "driver/gpio.h"
#include "freertos/FreeRTOS.h"
#include "freertos/task.h"

/*==============================================================================*/
/*  Macro:  DT_UINT                                                             */
/*  Desc:   Please change Test Point argument type for DT+ Project setting.     */
/*==============================================================================*/
#define DT_UINT unsigned int

/*==============================================================================*/
/*  Macro:  DT_INLINE                                                           */
/*  Desc:   Please use "static" instead of "inline" if "inline" cannot be used. */
/*==============================================================================*/
#define DT_INLINE static inline
/* #define	DT_INLINE	static */

/*==============================================================================*/
/*  Macro:  DT_ADD_EVENT_INFO                                                   */
/*  Desc:   Please set 1 when you add Event Value to Test Point.                */
/*==============================================================================*/
#define DT_ADD_EVENT_INFO 0

/*==============================================================================*/
/*  GPIO Pin Definitions for ESP32                                              */
/*==============================================================================*/
#define DT_GPIO_CLK GPIO_NUM_4	 /* DT+_1: IO4 - CLK */
#define DT_GPIO_CS GPIO_NUM_18	 /* DT+_2: IO18 - CS */
#define DT_GPIO_DAT0 GPIO_NUM_19 /* DT+_3: IO19 - DAT0 */
#define DT_GPIO_DAT1 GPIO_NUM_23 /* DT+_4: IO23 - DAT1 */

static uint32_t clk_level;

/*==============================================================================*/
/*  Func:   _TP_BusPortInit                                                     */
/*  Desc:   Please describe the code to initializes ports.                      */
/*==============================================================================*/
static void _TP_BusPortInit(void)
{
	/* Initialize GPIO pins for ESP32 */
	gpio_config_t io_conf = {};

	/* Configure CLK pin (GPIO4) */
	io_conf.intr_type = GPIO_INTR_DISABLE;
	io_conf.mode = GPIO_MODE_OUTPUT;
	io_conf.pin_bit_mask = ((1ULL << DT_GPIO_CLK) |
	                        (1ULL << DT_GPIO_CS) |
	                        (1ULL << DT_GPIO_DAT0) |
	                        (1ULL << DT_GPIO_DAT1));
	io_conf.pull_down_en = GPIO_PULLDOWN_DISABLE;
	io_conf.pull_up_en = GPIO_PULLUP_DISABLE;
	gpio_config(&io_conf);

	/* Set initial values - all pins HIGH */
	clk_level = 1;
	gpio_set_level(DT_GPIO_CLK, clk_level);
	gpio_set_level(DT_GPIO_CS, 1);
	gpio_set_level(DT_GPIO_DAT0, 1);
	gpio_set_level(DT_GPIO_DAT1, 1);
}

/*==============================================================================*/
/*  Func:   portReverseCLK                                                      */
/*  Desc:   Please describe the code to reverse CLK Port.                       */
/*==============================================================================*/
DT_INLINE void portReverseCLK(void)
{
	/* Toggle CLK pin */
	clk_level = !clk_level;
	gpio_set_level(DT_GPIO_CLK, clk_level);
}
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

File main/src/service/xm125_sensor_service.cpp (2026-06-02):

/**
 * @file xm125_sensor_service.cpp
 * @brief XM125（存在検知）用センササービス実装
 * @copyright Copyright (C) 2026, Heartland Data inc. All Rights Reserved.
 * SPDX-FileCopyrightText: 2026 Heartland Data inc.
 * SPDX-License-Identifier: Apache-2.0
 */

#include "xm125_sensor_service.hpp"
#include "esp_log.h"
#include <cstdio>
#include <vector>
#include "command_interface/communication_packet.hpp"
#include "command_interface/sensor_data_message.hpp"

namespace service
{
    namespace
    {
        // XM125測定設定カスタマイズ値
        // 変更したいパラメータだけコメントを外して値を編集する
        // #define kCustomSweepsPerFrame 16                                      // 1フレームあたりのスイープ数
        // #define kCustomInterFramePresenceTimeout 3                            // フレーム間プレゼンスタイムアウト（秒）
        // #define kCustomInterPhaseBoostEnabled 0                               // 位相ブースト有効（1=有効, 0=無効）
        // #define kCustomIntraDetectionEnabled 1                                // フレーム内検出有効（1=有効, 0=無効）
        // #define kCustomInterDetectionEnabled 1                                // フレーム間検出有効（1=有効, 0=無効）
        // #define kCustomFrameRate 12000                                        // フレームレート（mHz）
        // #define kCustomIntraDetectionThreshold 1300                           // フレーム内検出閾値
        // #define kCustomInterDetectionThreshold 1000                           // フレーム間検出閾値
        // #define kCustomInterFrameDeviationTimeConst 500                       // フレーム間偏差時定数（ms）
        // #define kCustomInterFrameFastCutoff 6000                              // フレーム間高速カットオフ（mHz）
        // #define kCustomInterFrameSlowCutoff 200                               // フレーム間低速カットオフ（mHz）
        // #define kCustomIntraFrameTimeConst 150                                // フレーム内時定数（ms）
        // #define kCustomIntraOutputTimeConst 300                               // フレーム内出力時定数（ms）
        // #define kCustomInterOutputTimeConst 2000                              // フレーム間出力時定数（ms）
        // #define kCustomAutoProfileEnabled 1                                   // 自動プロファイル有効（1=有効, 0=無効）
        // #define kCustomAutoStepLengthEnabled 1                                // 自動ステップ長有効（1=有効, 0=無効）
        // #define kCustomManualProfile 4                                        // 手動プロファイル（1-5: PROFILE1-5）
        // #define kCustomManualStepLength 72                                    // 手動ステップ長
        // #define kCustomStartMm 300                                            // 測定開始点（mm）
        // #define kCustomEndMm 2500                                             // 測定終了点（mm）
        // #define kCustomResetFiltersOnPrepare 1                                // フィルタリセット有効（1=有効, 0=無効）
        // #define kCustomHwaas 32                                               // ハードウェア加速平均サンプル
        // #define kCustomAutomaticSubsweeps 1                                   // 自動サブスイープ（1=有効, 0=無効）
        // #define kCustomSignalQuality 15000                                    // 信号品質
        // #define kCustomDetectionOnGpio 0                                      // GPIO出力による検出（1=有効, 0=無効）
        
        // I2C通信設定
        constexpr gpio_num_t kI2cMasterSclIo = GPIO_NUM_22; 
        constexpr gpio_num_t kI2cMasterSdaIo = GPIO_NUM_21; 
        constexpr i2c_port_t kI2cMasterNum = I2C_NUM_0;
        constexpr uint32_t kI2cMasterFreqHz = 400000;
        constexpr int kI2cMasterTimeoutMs = 1000;
        constexpr uint8_t kXm125Address = 0x52;
        
        // XM125固有のGPIO設定
        constexpr gpio_num_t kWakeupPin = GPIO_NUM_25;
        constexpr gpio_num_t kInterruptPin = GPIO_NUM_26;
        constexpr int kWakeupMaxRetries = 3;                     ///< ウェイクアップ最大リトライ回数
        
        const char *kTag = "Xm125SensorService";                 ///< ログ出力用タグ

    }

    /**
     * @brief コンストラクタ
     * @param handler センサータスクハンドラへのポインタ
     * @details XM125センサーサービスのインスタンスを生成します。
     */
    Xm125SensorService::Xm125SensorService(Task::ISensorTaskHandler *handler)
        : handler_(handler),
          i2cInitialized_(false),
          sensorInitialized_(false),
          busHandle_(nullptr),
          devHandle_(nullptr) {}

    /**
     * @brief デストラクタ
     * @details 使用したリソースを依存関係の逆順で解放します。
     */
    Xm125SensorService::~Xm125SensorService()
    {
        // センサーの終了処理
        if (sensorInitialized_) {
            xm125_deinit(&xm125Handle_);
        }
        
        // I2Cデバイスの削除
        if (devHandle_ != nullptr) {
            i2c_master_bus_rm_device(devHandle_);
        }
        
        // I2Cバスの削除
        if (busHandle_ != nullptr) {
            i2c_del_master_bus(busHandle_);
        }
        
        ESP_LOGW(kTag, "XM125 service resources cleaned up");
    }

    /**
     * @brief サービスの初期化
     * @retval true 初期化成功
     * @retval false 初期化失敗
     * @details I2C通信とXM125センサーの初期化を順次実行します。
     */
    bool Xm125SensorService::Initialize()
    {
        if (!InitializeI2c()) 
            return false;
        if (!InitializeXm125()) 
            return false;
        return true;
    }

    /**
     * @brief センサーデータの周期的な取得と送信
     * @details プレゼンス検出結果を読み取り、ログ出力します。
     */
    void Xm125SensorService::Run()
    {
        xm125_presence_result_t result;
        esp_err_t ret = xm125_read_presence_result(&xm125Handle_, &result);
        
        if (ret == ESP_OK) {
            // プレゼンス検出時のみINFOレベルでログ出力
            if (result.presence_detected || result.presence_detected_sticky) {
                ESP_LOGI(kTag, "Presence detected - Distance: %ld mm, Intra: %ld, Inter: %ld",
                         result.distance_mm, result.intra_score, result.inter_score);
            } else {
                // 検出なしの場合はDEBUGレベル（通常は非表示）
                ESP_LOGD(kTag, "No presence detected");
            }
            
            // センサーデータをJSON化して送信
            SendXm125SensorData(&result);
        } else {
            ESP_LOGE(kTag, "Failed to read presence result: %s", esp_err_to_name(ret));
        }
    }

    /**
     * @brief センサーデータをJSON化・パケット化して送信
     * @param result プレゼンス検出結果構造体へのポインタ
     * @details 検出結果をJSONに変換してバイナリパケット化し、送信します
     */
    void Xm125SensorService::SendXm125SensorData(const xm125_presence_result_t *result)
    {
        // センサーデータをMapに変換
        Domain::CommandInterface::SensorDataMap dataMap;
        dataMap["detected"] = result->presence_detected;                  // 現在の検出状態
        dataMap["detected_sticky"] = result->presence_detected_sticky;    // 検出履歴（タイムアウトまで保持）
        dataMap["detector_error"] = result->detector_error;               // エラーフラグ
        dataMap["distance_mm"] = result->distance_mm;                     // 検出距離（検出なし時は-1）
        dataMap["intra_score"] = result->intra_score;                     // フレーム内スコア
        dataMap["inter_score"] = result->inter_score;                     // フレーム間スコア

        // JSON文字列生成
        auto msg = Domain::CommandInterface::SensorDataMessage::Create("XM125", dataMap);
        std::string json = msg->ToJsonString();
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

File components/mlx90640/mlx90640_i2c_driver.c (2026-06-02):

/**
 * @file mlx90640_i2c_driver.c
 * @brief MLX90640 I2C driver implementation for ESP32-IDF
 * @copyright (C) 2017 Melexis N.V.
 * @copyright (C) 2025 Heartland.Data Inc.
 *
 * Licensed under the Apache License, Version 2.0 (the "License");
 * you may not use this file except in compliance with the License.
 * You may obtain a copy of the License at
 *
 *     http://www.apache.org/licenses/LICENSE-2.0
 *
 * Unless required by applicable law or agreed to in writing, software
 * distributed under the License is distributed on an "AS IS" BASIS,
 * WITHOUT WARRANTIES OR CONDITIONS OF ANY KIND, either express or implied.
 * See the License for the specific language governing permissions and
 * limitations under the License.
 *
 * Based on the Melexis MLX90640 library:
 *   https://github.com/melexis/mlx90640-library
 * Adapted for Arduino by SparkFun Electronics:
 *   https://github.com/sparkfun/Qwiic_IR_Array_MLX90640
 * Ported to ESP32-IDF and modified by Heartland.Data Inc.
 * SPDX-FileCopyrightText: 2017 Melexis N.V.
 * SPDX-FileCopyrightText: 2025 Heartland.Data Inc.
 * SPDX-License-Identifier: Apache-2.0
 */

#include "mlx90640_i2c_driver.h"
#include "esp_log.h"
#include "esp_err.h"
#include "freertos/FreeRTOS.h"
#include "freertos/task.h"
#include "driver/i2c_master.h"

static const char *TAG = "MLX90640_I2C";

static i2c_master_bus_handle_t s_bus_handle = NULL;
static i2c_master_dev_handle_t s_dev_handle = NULL;
static bool is_initialized = false;

/**
 * @brief Initialize I2C driver for MLX90640
 */
int MLX90640_I2CInit(i2c_port_t port, int sda_pin, int scl_pin, uint32_t freq_hz, uint8_t device_address)
{
    if (is_initialized) {
        ESP_LOGW(TAG, "I2C already initialized");
        return ESP_OK;
    }

    // Initialize I2C master bus
    i2c_master_bus_config_t bus_config = {
        .i2c_port = port,
        .sda_io_num = sda_pin,
        .scl_io_num = scl_pin,
        .clk_source = I2C_CLK_SRC_DEFAULT,
        .glitch_ignore_cnt = 7,
        .flags.enable_internal_pullup = true,
    };

    esp_err_t err = i2c_new_master_bus(&bus_config, &s_bus_handle);
    if (err != ESP_OK) {
        ESP_LOGE(TAG, "Failed to create I2C master bus: %s", esp_err_to_name(err));
        return -1;
    }

    // Add MLX90640 device to the bus
    i2c_device_config_t dev_config = {
        .dev_addr_length = I2C_ADDR_BIT_LEN_7,
        .device_address = device_address,
        .scl_speed_hz = freq_hz,
    };

    err = i2c_master_bus_add_device(s_bus_handle, &dev_config, &s_dev_handle);
    if (err != ESP_OK) {
        ESP_LOGE(TAG, "Failed to add MLX90640 device (0x%02X): %s", device_address, esp_err_to_name(err));
        i2c_del_master_bus(s_bus_handle);
        s_bus_handle = NULL;
        return -1;
    }

    is_initialized = true;
    ESP_LOGI(TAG, "I2C initialized successfully on port %d with device 0x%02X", port, device_address);
    return ESP_OK;
}

/**
 * @brief Deinitialize I2C driver
 */
int MLX90640_I2CDeinit(i2c_port_t port)
{
    if (!is_initialized) {
        ESP_LOGW(TAG, "I2C not initialized");
        return ESP_OK;
    }

    esp_err_t err = ESP_OK;

    // Remove device from bus
    if (s_dev_handle != NULL) {
        err = i2c_master_bus_rm_device(s_dev_handle);
        if (err != ESP_OK) {
            ESP_LOGE(TAG, "Failed to remove device from I2C bus: %s", esp_err_to_name(err));
        }
        s_dev_handle = NULL;
    }

    // Delete master bus
    if (s_bus_handle != NULL) {
        err = i2c_del_master_bus(s_bus_handle);
        if (err != ESP_OK) {
            ESP_LOGE(TAG, "Failed to delete I2C master bus: %s", esp_err_to_name(err));
            return -1;
        }
        s_bus_handle = NULL;
    }

    is_initialized = false;
    ESP_LOGI(TAG, "I2C deinitialized successfully");
    return ESP_OK;
}

/**
 * @brief Read data from MLX90640 via I2C
 */
int MLX90640_I2CRead(uint8_t deviceAddress, unsigned int startAddress, unsigned int nWordsRead, uint16_t *data)
{
    if (!is_initialized || s_dev_handle == NULL) {
        ESP_LOGE(TAG, "I2C not initialized");
        return -1;
    }

    if (data == NULL || nWordsRead == 0) {
        ESP_LOGE(TAG, "Invalid parameters");
        return -1;
    }

    uint8_t write_buf[2];
    write_buf[0] = (startAddress >> 8) & 0xFF;  // High byte
    write_buf[1] = startAddress & 0xFF;         // Low byte

    // Read data (each word is 2 bytes)
    uint8_t *read_buf = (uint8_t *)data;
    size_t read_size = nWordsRead * 2;

    // Use write-read transaction for register access
    esp_err_t err = i2c_master_transmit_receive(s_dev_handle, write_buf, 2, read_buf, read_size, 1000);
    if (err != ESP_OK) {
        ESP_LOGE(TAG, "Failed to read data: %s", esp_err_to_name(err));
        return -1;
    }

    // Convert from big-endian to little-endian
    for (unsigned int i = 0; i < nWordsRead; i++) {
        uint8_t temp = read_buf[i * 2];
        read_buf[i * 2] = read_buf[i * 2 + 1];
        read_buf[i * 2 + 1] = temp;
    }

    return 0;
}

/**
 * @brief Write data to MLX90640 via I2C
 */
int MLX90640_I2CWrite(uint8_t deviceAddress, unsigned int writeAddress, uint16_t data)
{
    if (!is_initialized || s_dev_handle == NULL) {
        ESP_LOGE(TAG, "I2C not initialized");
        return -1;
    }

    uint8_t write_buf[4];
    write_buf[0] = (writeAddress >> 8) & 0xFF;  // Address high byte
    write_buf[1] = writeAddress & 0xFF;         // Address low byte
    write_buf[2] = (data >> 8) & 0xFF;          // Data high byte
    write_buf[3] = data & 0xFF;                 // Data low byte

    esp_err_t err = i2c_master_transmit(s_dev_handle, write_buf, 4, 1000);
    if (err != ESP_OK) {
        ESP_LOGE(TAG, "Failed to write data: %s", esp_err_to_name(err));
        return -1;
    }

    return 0;
}

/**
 * @brief Set I2C frequency
 */
void MLX90640_I2CFreqSet(uint32_t freq_hz)
{
    if (!is_initialized) {
        ESP_LOGW(TAG, "I2C not initialized, cannot set frequency");
        return;
    }

    // Note: In ESP32-IDF, changing frequency at runtime requires reconfiguration
    ESP_LOGI(TAG, "Frequency set to %ld Hz (requires reinitialization)", freq_hz);
}
